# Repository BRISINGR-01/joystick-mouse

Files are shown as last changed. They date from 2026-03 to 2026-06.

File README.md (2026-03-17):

# Joystick Mouse Prototype

## Overview

This project demonstrates a simple joystick-based mouse using an Arduino and Python. The Arduino reads a 2-axis joystick and a button, sending X/Y movement and click state over serial. A Python script interprets the data and moves the system cursor using ydotool.

The goal is to create a keyboard-adjacent pointing device as an alternative to a traditional mouse.

## Hardware Requirements

- Arduino Nano (or compatible board)
- 2-axis analog joystick
- Push button (for primary click)
- USB cable for serial connection

## Connections
- Joystick X → A2
- Joystick Y → A4
- Button → A1 (with INPUT_PULLUP)

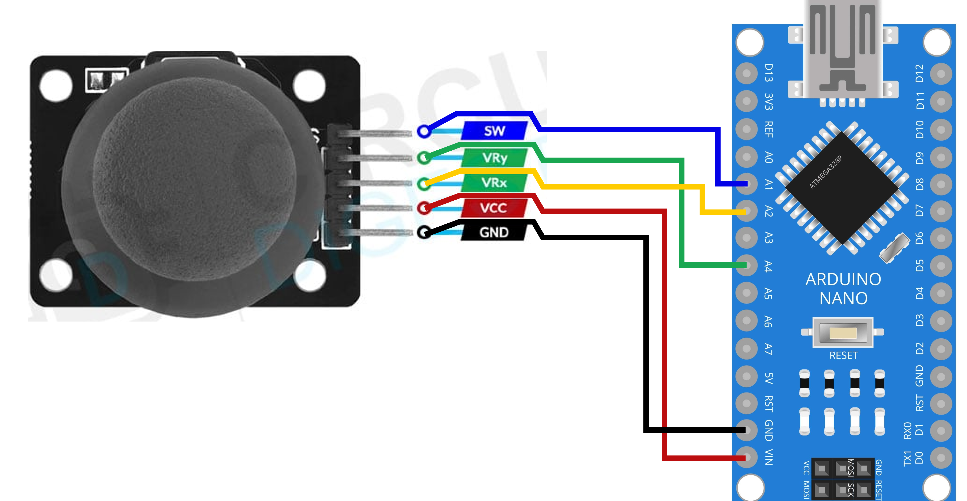
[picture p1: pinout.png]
pinout


## Software Requirements
- Python 3
- ezButton library (Arduino)
- ydotool (Linux)

### What it does
- Reads joystick axes and button state
- Maps analog joystick values to a range of -MOUSE_SENSITIVITY to MOUSE_SENSITIVITY
- Applies a small deadzone to avoid drift
- Sends data over serial in the format:
- X_value:Y_value:button_state

#### Python Script

- Opens serial port to Arduino (/dev/ttyUSB0)
- Reads and parses serial data
- Moves cursor with ydotool according to X/Y values
- Triggers mouse click on button press

#### Behavior
- Joystick movement → cursor movement
- Button press → left mouse click
- Supports continuous movement with adjustable delay (time.sleep(0.02))

## Usage

0) Install ydotool and ensure permissions allow cursor control.
  
1) Connect Arduino to PC and upload the sketch. Might have to unlock port with
```
chmod 777 /dev/ACM*  
chmod 777 /dev/tty*
```
2) Set up the python environment. Ex: `pip install pyserial`

3) Set the port in the python script and run it with:

`python3 joystick_mouse.py`

Move the joystick to control the cursor; press the button to click.

## Notes

Sensitivity and deadzone can be adjusted in the Arduino sketch (MOUSE_SENSITIVITY and threshold).

The script currently uses Linux-specific ydotool; adaptation is needed for other OSes.

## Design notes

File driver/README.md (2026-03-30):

# Virtual Mouse (uinput)

A minimal C++ project that creates and controls a virtual mouse using the Linux **uinput** subsystem.

## Project Structure

```
├── CMakeLists.txt
├── include
├── README.md
├── scripts
│   ├── build.sh             # Build project
│   ├── clean.sh             # Clean build files
│   └── run.sh               # Run executable
└── src 
```

## Requirements

* Linux (with `/dev/uinput`)
* C++ compiler (g++)
* CMake

## Build

```bash
chmod +x ./scripts/build.sh
./scripts/build.sh
```
or

`bash -c ./scripts/build.sh`

## Run

```bash
chmod +x ./scripts/run.sh
./scripts/run.sh
```

Or:

`bash -c ./scripts/run.sh`

\*requires *sudo* priviliges

## How it works

The C++ code uses the **uinput** interface provided by the system to emulate a virtual mouse and controll features like cursor movement and button clicks

## Features

* Relative mouse movement
* Mouse button press/release
* Scroll support
* Adjustable sensitivity

## Notes

* Requires root or proper udev permissions
* Works on both X11 and Wayland
* No external libraries required

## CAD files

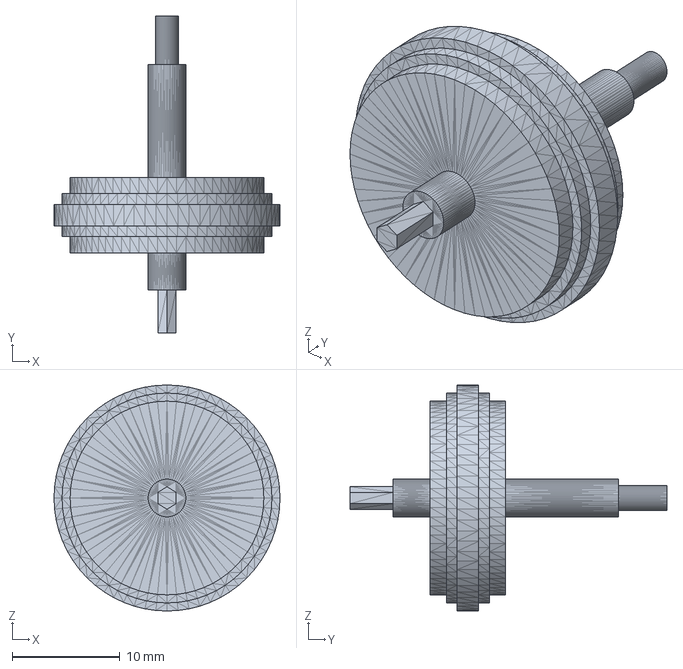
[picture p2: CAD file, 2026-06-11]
hardware/design/stl/wheel.step
21.0 x 29.4 x 21.0 mm

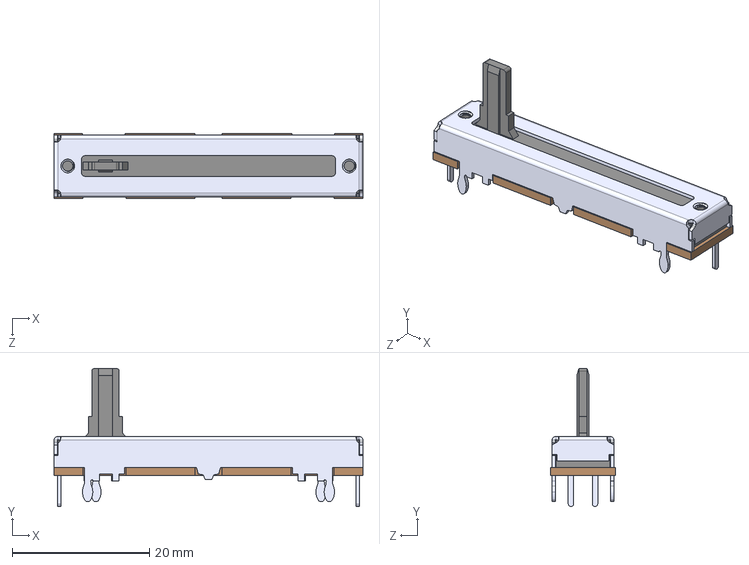
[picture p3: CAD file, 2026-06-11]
hardware/design/stl/slider.step
45.0 x 20.1 x 9.40 mm

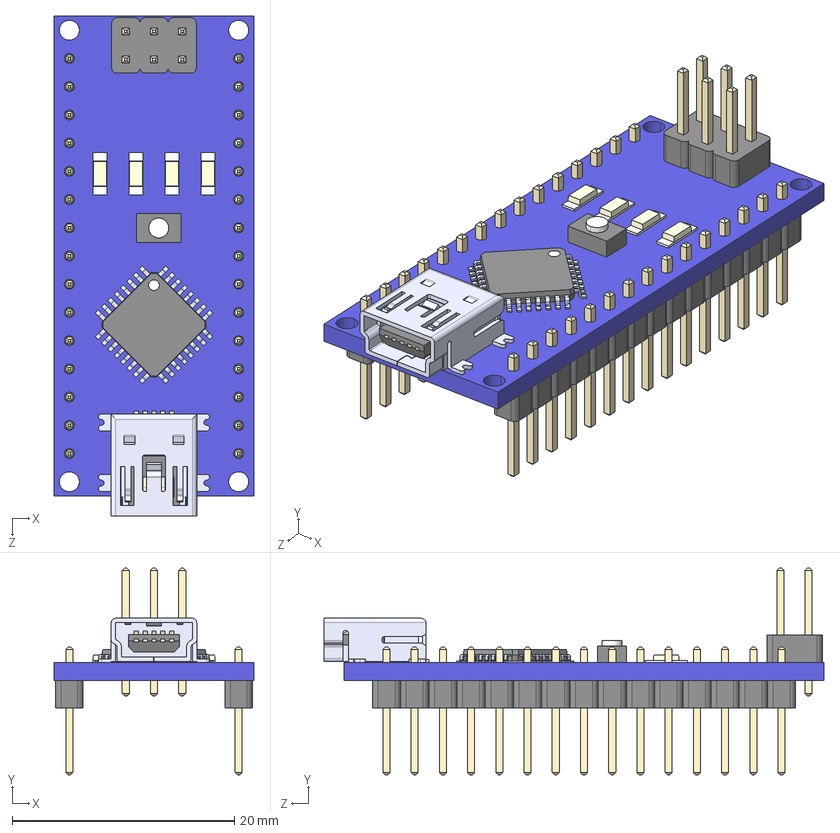
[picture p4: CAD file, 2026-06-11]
hardware/design/stl/nano.STEP
18.0 x 18.6 x 45.0 mm

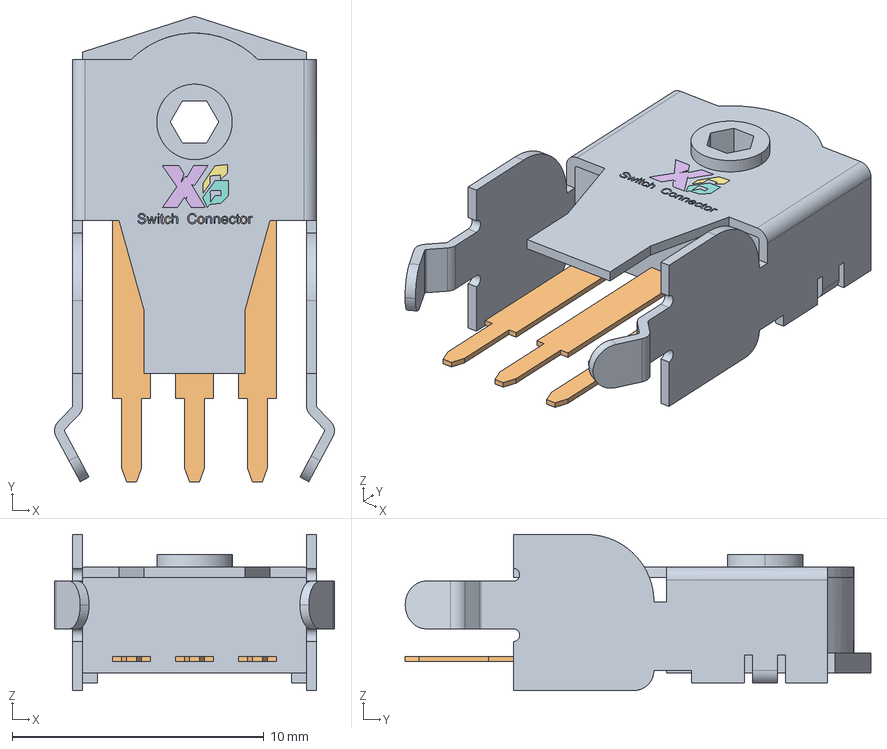
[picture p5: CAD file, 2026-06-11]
hardware/design/stl/rotary-encoder.stp
11.1 x 18.5 x 6.20 mm

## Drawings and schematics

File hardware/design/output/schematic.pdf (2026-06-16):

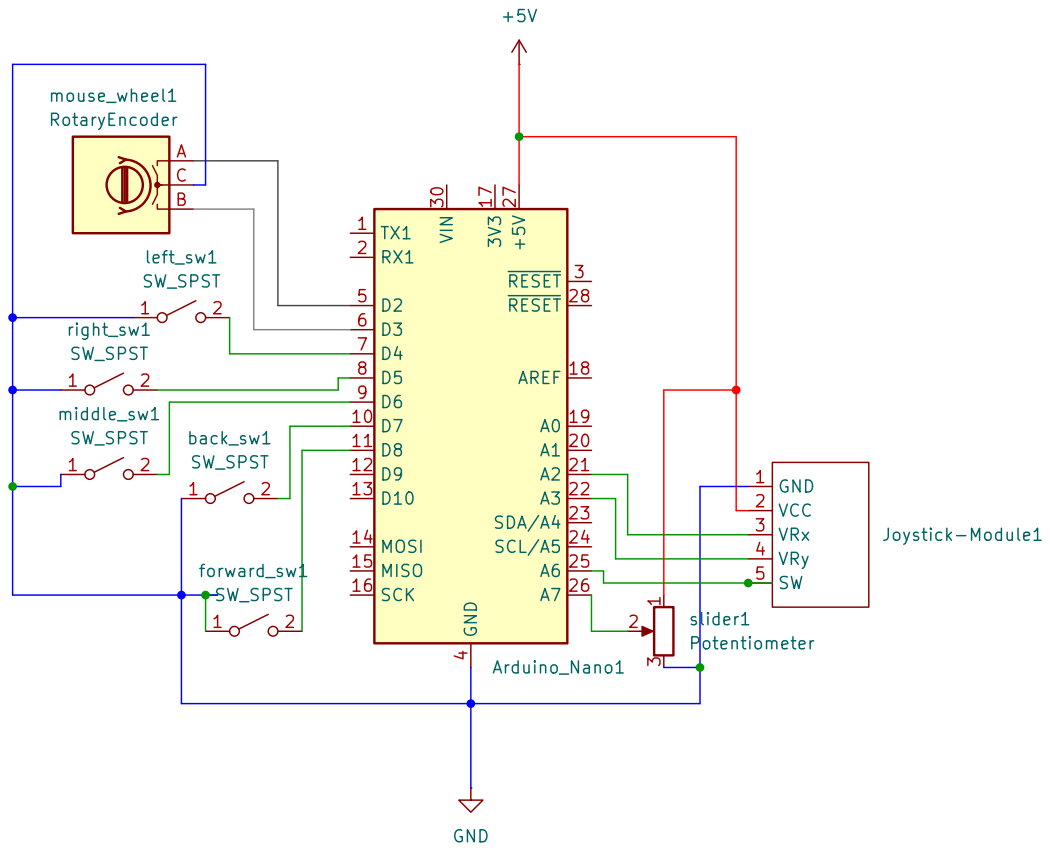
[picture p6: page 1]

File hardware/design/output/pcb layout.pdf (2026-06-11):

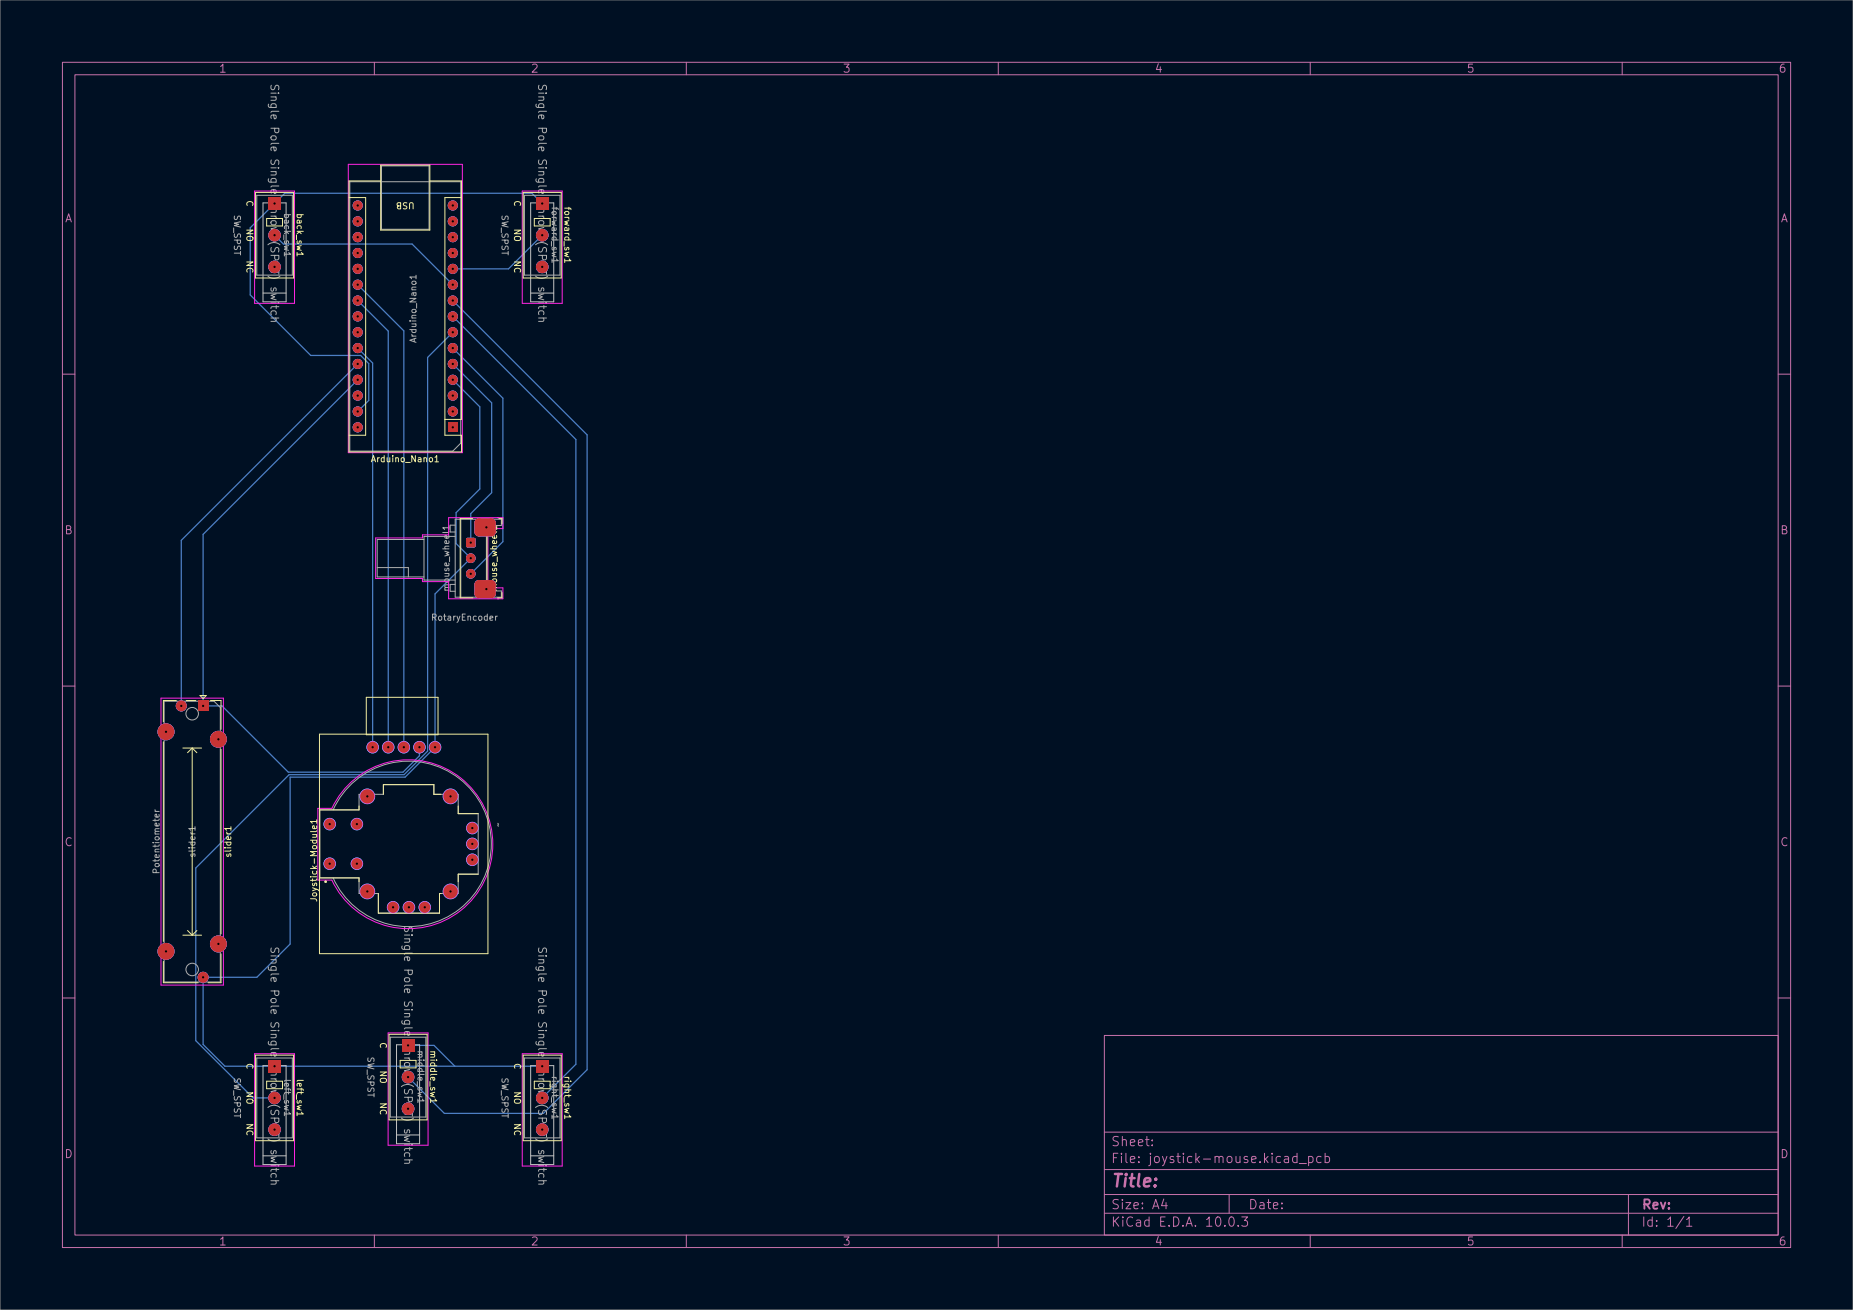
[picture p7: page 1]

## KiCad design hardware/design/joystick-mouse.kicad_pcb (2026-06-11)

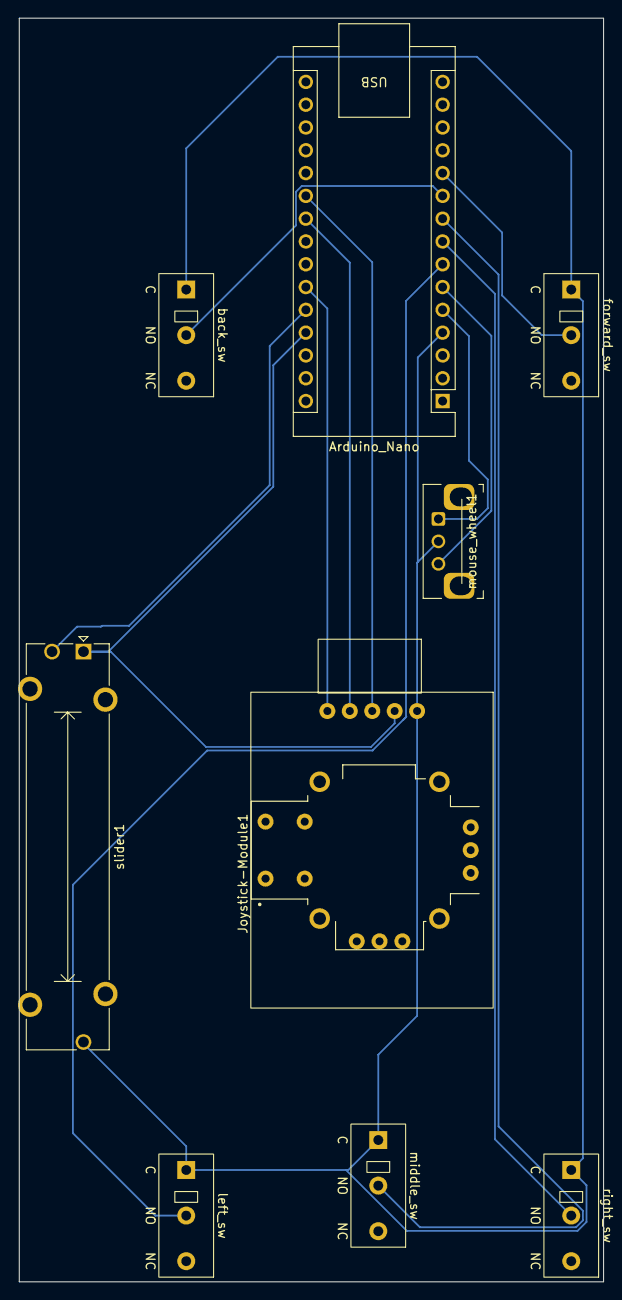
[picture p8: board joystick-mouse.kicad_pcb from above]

Board: 2 copper layers, 65.1 x 140.8 mm, 9 parts (0 on the bottom side), 13 nets.

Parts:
Arduino_Nano: Arduino_Nano
Joystick-Module1: ky-023_joystick
back_sw: SW_SPST; SW_XKB_DM1-16UP-1
forward_sw: SW_SPST; SW_XKB_DM1-16UP-1
left_sw: SW_SPST; SW_XKB_DM1-16UP-1
middle_sw: SW_SPST; SW_XKB_DM1-16UP-1
mouse_wheel1: RotaryEncoder; RotaryEncoder_Bourns_Horizontal_PEC12R-2x17F-Nxxxx
right_sw: SW_SPST; SW_XKB_DM1-16UP-1
slider1: Potentiometer; Potentiometer_Bourns_PTA3043_Single_Slide

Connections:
+5V: Arduino_Nano.27 (+5V), Joystick-Module1.2 (VCC), slider1.1
GND: Arduino_Nano.4 (GND), Arduino_Nano.29 (GND), Joystick-Module1.1 (GND), back_sw.1 (A), forward_sw.1 (A), left_sw.1 (A), middle_sw.1 (A), mouse_wheel1.C, right_sw.1 (A), slider1.3
unnamed: Arduino_Nano.21 (A2), Joystick-Module1.3 (VRx)
unnamed: Arduino_Nano.22 (A3), Joystick-Module1.4 (VRy)
unnamed: Arduino_Nano.25 (A6), Joystick-Module1.5 (SW)
unnamed: Arduino_Nano.26 (A7), slider1.2
unnamed: Arduino_Nano.5 (D2), mouse_wheel1.A
unnamed: Arduino_Nano.6 (D3), mouse_wheel1.B
unnamed: Arduino_Nano.7 (D4), left_sw.2 (B)
unnamed: Arduino_Nano.8 (D5), right_sw.2 (B)
unnamed: Arduino_Nano.9 (D6), middle_sw.2 (B)
unnamed: Arduino_Nano.10 (D7), back_sw.2 (B)
unnamed: Arduino_Nano.11 (D8), forward_sw.2 (B)

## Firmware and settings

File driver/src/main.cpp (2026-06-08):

#include <exception.hpp>
#include <receiver.hpp>
#include <data_constants.hpp>
#include <uinput_backend.hpp>
#include <mouse.hpp>
#include <utils.hpp>
#include <serial_comm.hpp>

int main()
{
    char *dev_name = std::getenv("DEVNAME");
    if (dev_name == NULL)
    {
        log_err("No port was provided");
        exit(-1);
    }

    const string port_name = dev_name;

    int port = open_port(port_name);

    auto receiver = Receiver();
    try
    {
        receiver.connect(port);
    }
    catch (const std::exception &e)
    {
        close(port);
        exit(-1);
    }

    Mouse mouse(std::make_unique<UInputBackend>(DEVICE_NAME, VENDOR_ID, PRODUCT_ID));
    while (true)
    {
        if (!receiver.wait())
            continue;

        switch (receiver.process())
        {
        case Receiver::Status::OK:
            process_data(receiver, mouse);
            break;
        case Receiver::Status::NoAction:
            break;
        case Receiver::Status::Disconnected:
            write_log("Device disconnected");
            break;
        }
    }

    close(port);

    return 0;
}

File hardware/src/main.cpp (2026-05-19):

#include <Arduino.h>

#include <joystick.hpp>
#include <rotary_encoder.hpp>
#include <buttons.hpp>
#include <utils.hpp>
#include <data_constants.hpp>

Joystick joystick(A2, A4, 13);
RotaryEncoder rotary_encoder(3, 2);
Buttons btns(4, 5, 6, 7, 8);
data_unit slider_val;

data_unit prev_data[DATA_SIZE] = {};
data_unit data[DATA_SIZE] = {};

void setup()
{
  Serial.begin(9600);
  joystick.setup();
  rotary_encoder.setup();

  pinMode(SLIDER_PIN, INPUT);
}

void fill_data()
{
  data[BUTTON_IDX] = btns.encode_data(joystick);
  data[X_IDX] = joystick.x;
  data[Y_IDX] = joystick.y;
  data[SCROLL_IDX] = rotary_encoder.val;
  data[SLIDER_IDX] = slider_val;
}

void loop()
{
  delay(50);

  joystick.update();
  rotary_encoder.update();
  btns.update();
  slider_val = read_slider();

  fill_data();

  if (should_send(data, prev_data))
  {
    size_t size = DATA_SIZE * sizeof(data_unit);
    Serial.write(data, size);
    memcpy(prev_data, data, size);
  }
  else
  {
    delay(150);
  }
}

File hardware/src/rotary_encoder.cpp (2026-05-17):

#include <rotary_encoder.hpp>

int aPin = 0;
int bPin = 0;
volatile int encoderCount = 0;

RotaryEncoder::RotaryEncoder(int a, int b) : val(0)
{
    aPin = a;
    bPin = b;
}

void handleEncoderInterrupt()
{
    static int lastState = 0;
    uint8_t state = (digitalRead(aPin) << 1) | digitalRead(bPin);

    if ((lastState == 0b00 && state == 0b01) ||
        (lastState == 0b01 && state == 0b11) ||
        (lastState == 0b11 && state == 0b10) ||
        (lastState == 0b10 && state == 0b00))
    {
        encoderCount++;
    }
    else if ((lastState == 0b00 && state == 0b10) ||
             (lastState == 0b10 && state == 0b11) ||
             (lastState == 0b11 && state == 0b01) ||
             (lastState == 0b01 && state == 0b00))
    {
        encoderCount--;
    }

    lastState = state;
}

void RotaryEncoder::setup()
{
    pinMode(aPin, INPUT_PULLUP);
    pinMode(bPin, INPUT_PULLUP);
    int a = digitalPinToInterrupt(aPin);
    int b = digitalPinToInterrupt(bPin);

    if (a == -1 || b == -1)
    {
        Serial.println("Pin A or B is not avaliable as interrupt pin");
        exit(1);
    }

    attachInterrupt(a, handleEncoderInterrupt, CHANGE);
    attachInterrupt(b, handleEncoderInterrupt, CHANGE);
}

void RotaryEncoder::update()
{
    val = constrain(encoderCount, -127, 127);
    encoderCount = 0;
}

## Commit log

2026-03-30 create uiinput driver
2026-06-08 unit tests
    [joystick-mouse.kicad_pcb, joystick-mouse.kicad_sch]
2026-06-11 finish pcb
    [joystick-mouse.kicad_pcb, joystick-mouse.kicad_sch, joystick.kicad_pcb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]
